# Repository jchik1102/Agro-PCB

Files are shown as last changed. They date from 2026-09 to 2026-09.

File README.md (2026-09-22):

# Agrobot Power Board

Native KiCad schematic and four-layer PCB draft for a regulated 12 V input with separate 5 V and 3.3 V buck converters. Designed as a documented portfolio project; **not a fabrication release or tested hardware**.

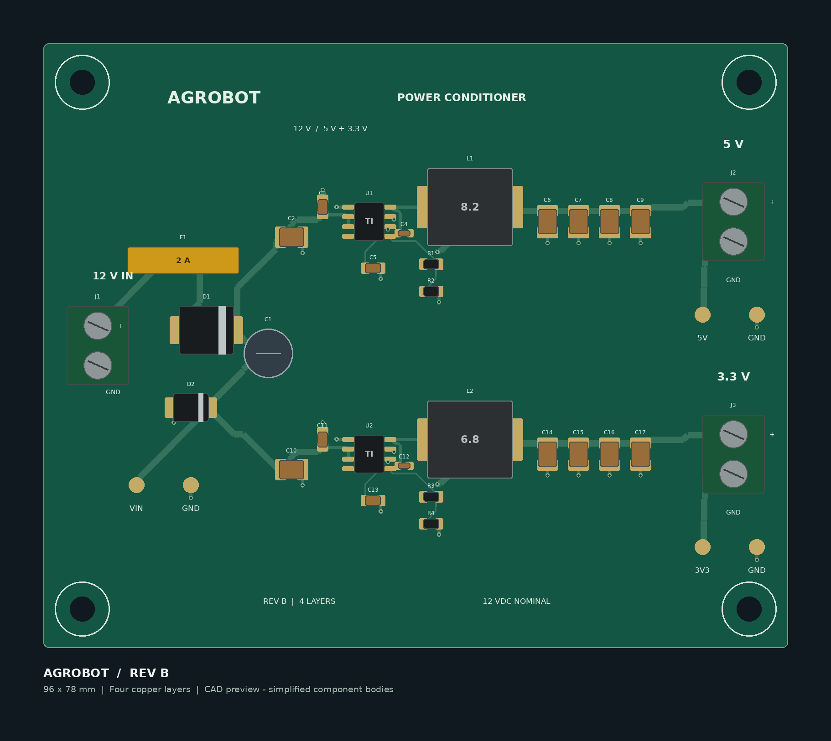
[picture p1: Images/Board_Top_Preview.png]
Board preview


## Open it

1. Install KiCad 9 or newer, including its standard applications.
2. Extract this entire ZIP. Keep the project and Libraries folder together.
3. Open `Agrobot_Power_Board.kicad_pro` in KiCad.
4. Open the schematic with the Schematic Editor button, or the board with the PCB Editor button.
5. In PCB Editor, press **B** to fill the ground zones, then save. If any load/parse error appears, stop and send a screenshot of the complete error.
6. Press **Alt+3** for KiCad's 3D viewer. Included 3D bodies are simplified representations, not manufacturer CAD models.

Ground zones have been defined but are delivered unfilled. Until step 5, ground connections will appear incomplete. The supplied images and PDF are authoring previews, not screenshots or exports from KiCad.

## Requirements and status

| Item | Target / implementation | Evidence status |
| --- | --- | --- |
| Input | Regulated 12 V DC, screw terminal | Nominal design input; not qualified for battery/automotive transients |
| 5 V output | 0.75 A continuous, 1.5 A peak | Design target; load and thermal testing pending |
| 3.3 V output | 0.5 A continuous, 1.0 A peak | Design target; load and thermal testing pending |
| Ripple | 20 mVpp / 10 mVpp respectively, 20 MHz bandwidth | Targets only; not simulated or measured |
| Protection | Resettable input fuse, reverse-polarity diode, TVS clamp | Component-level proposal; coordination review pending |
| Board | 96 x 78 mm, four copper layers, four 3.2 mm mounting holes | Native layout draft |
| Ground | Two internal planes plus outer-layer zones | Fill locally before native DRC |

The two LMR33630 converters use separate inductors, feedback networks, and output capacitors. No microcontroller or sensors are included: this is the Agrobot **power-conditioning board** only. Peak duration is unspecified; no guaranteed peak-duration capability is claimed.

## Contents

- `.kicad_pro`, `.kicad_sch`, `.kicad_pcb`: editable native project.
- `Libraries`: project-local symbols, footprints, simplified 3D models.
- `Documentation/Schematic_Preview.pdf`: immediately viewable schematic preview.
- `Images`: illustrative top-board preview.

## Publishing on GitHub

Upload this folder's contents after reviewing the design. Keep the libraries and relative folder structure intact. The included `.gitignore` excludes local report runs and editor backups. You can deliberately add selected native PDFs, renders, and reviewed reports later.

An accurate project description is: "Developed a KiCad power-conditioning PCB draft for a 12 V input and 5 V/3.3 V outputs, with input protection and documented load/ripple targets. Fabrication and bench validation pending."

Do not describe the ripple or current targets as measured results, or this project as completed in Altium. AI-assisted authoring should be described accurately when relevant to portfolio or academic requirements.

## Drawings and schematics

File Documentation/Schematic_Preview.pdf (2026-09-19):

# AGROBOT / DUAL-RAIL POWER CONDITIONER

## 12 V INPUT | 5 V + 3.3 V | REV B | NATIVE KiCad

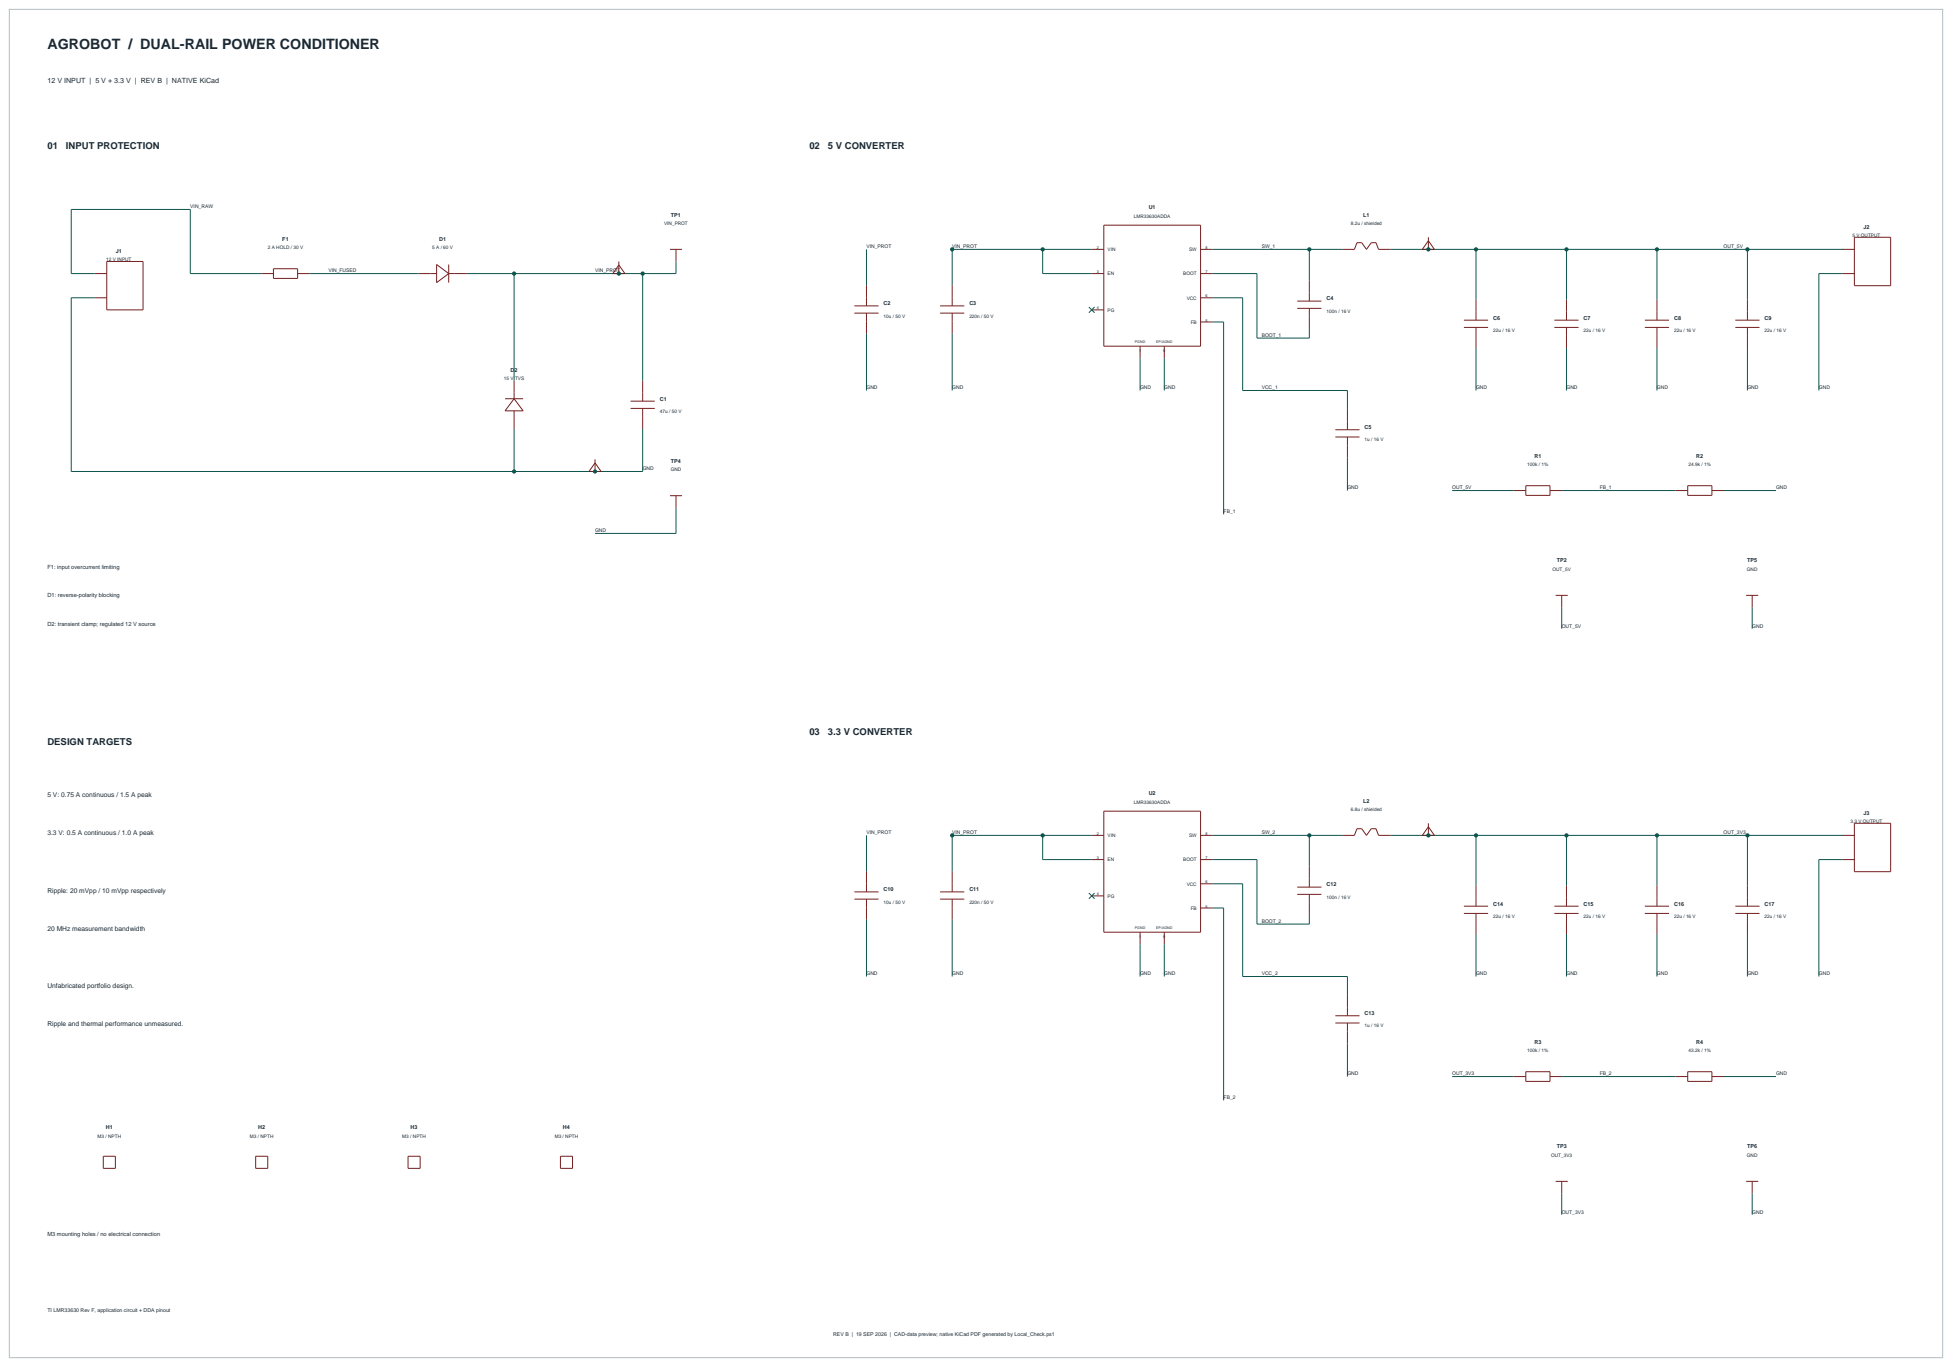
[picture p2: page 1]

D2: transient clamp; regulated 12 V source

Ripple: 20 mVpp / 10 mVpp respectively

Ripple and thermal performance unmeasured.

M3 mounting holes / no electrical connection

TI LMR33630 Rev F, application circuit + DDA pinout

REV B | 19 SEP 2026 | CAD-data preview; native KiCad PDF generated by Local_Check.ps1

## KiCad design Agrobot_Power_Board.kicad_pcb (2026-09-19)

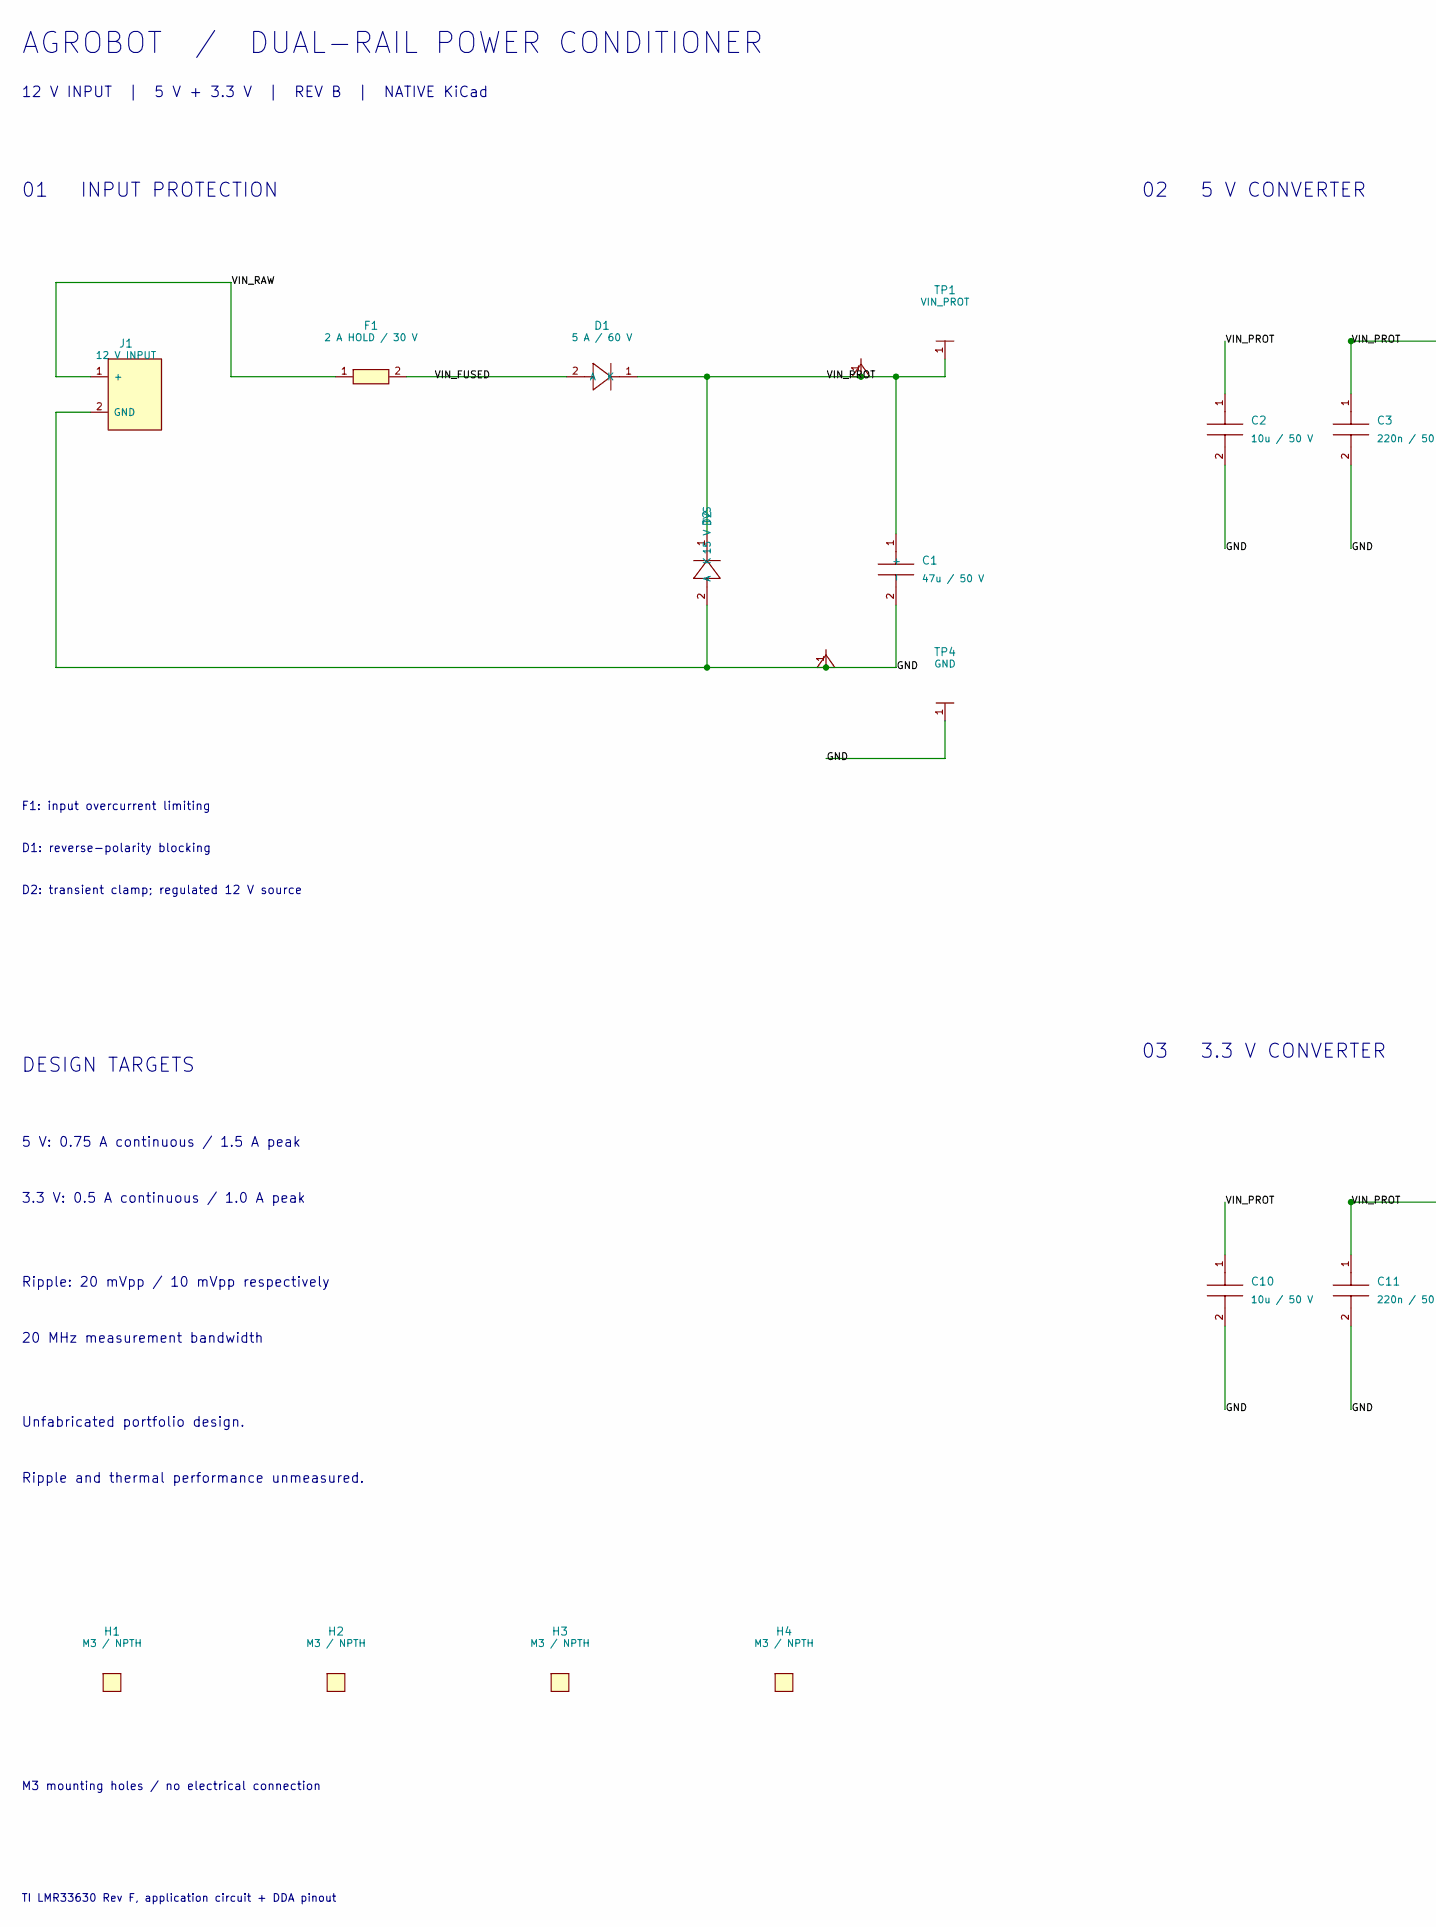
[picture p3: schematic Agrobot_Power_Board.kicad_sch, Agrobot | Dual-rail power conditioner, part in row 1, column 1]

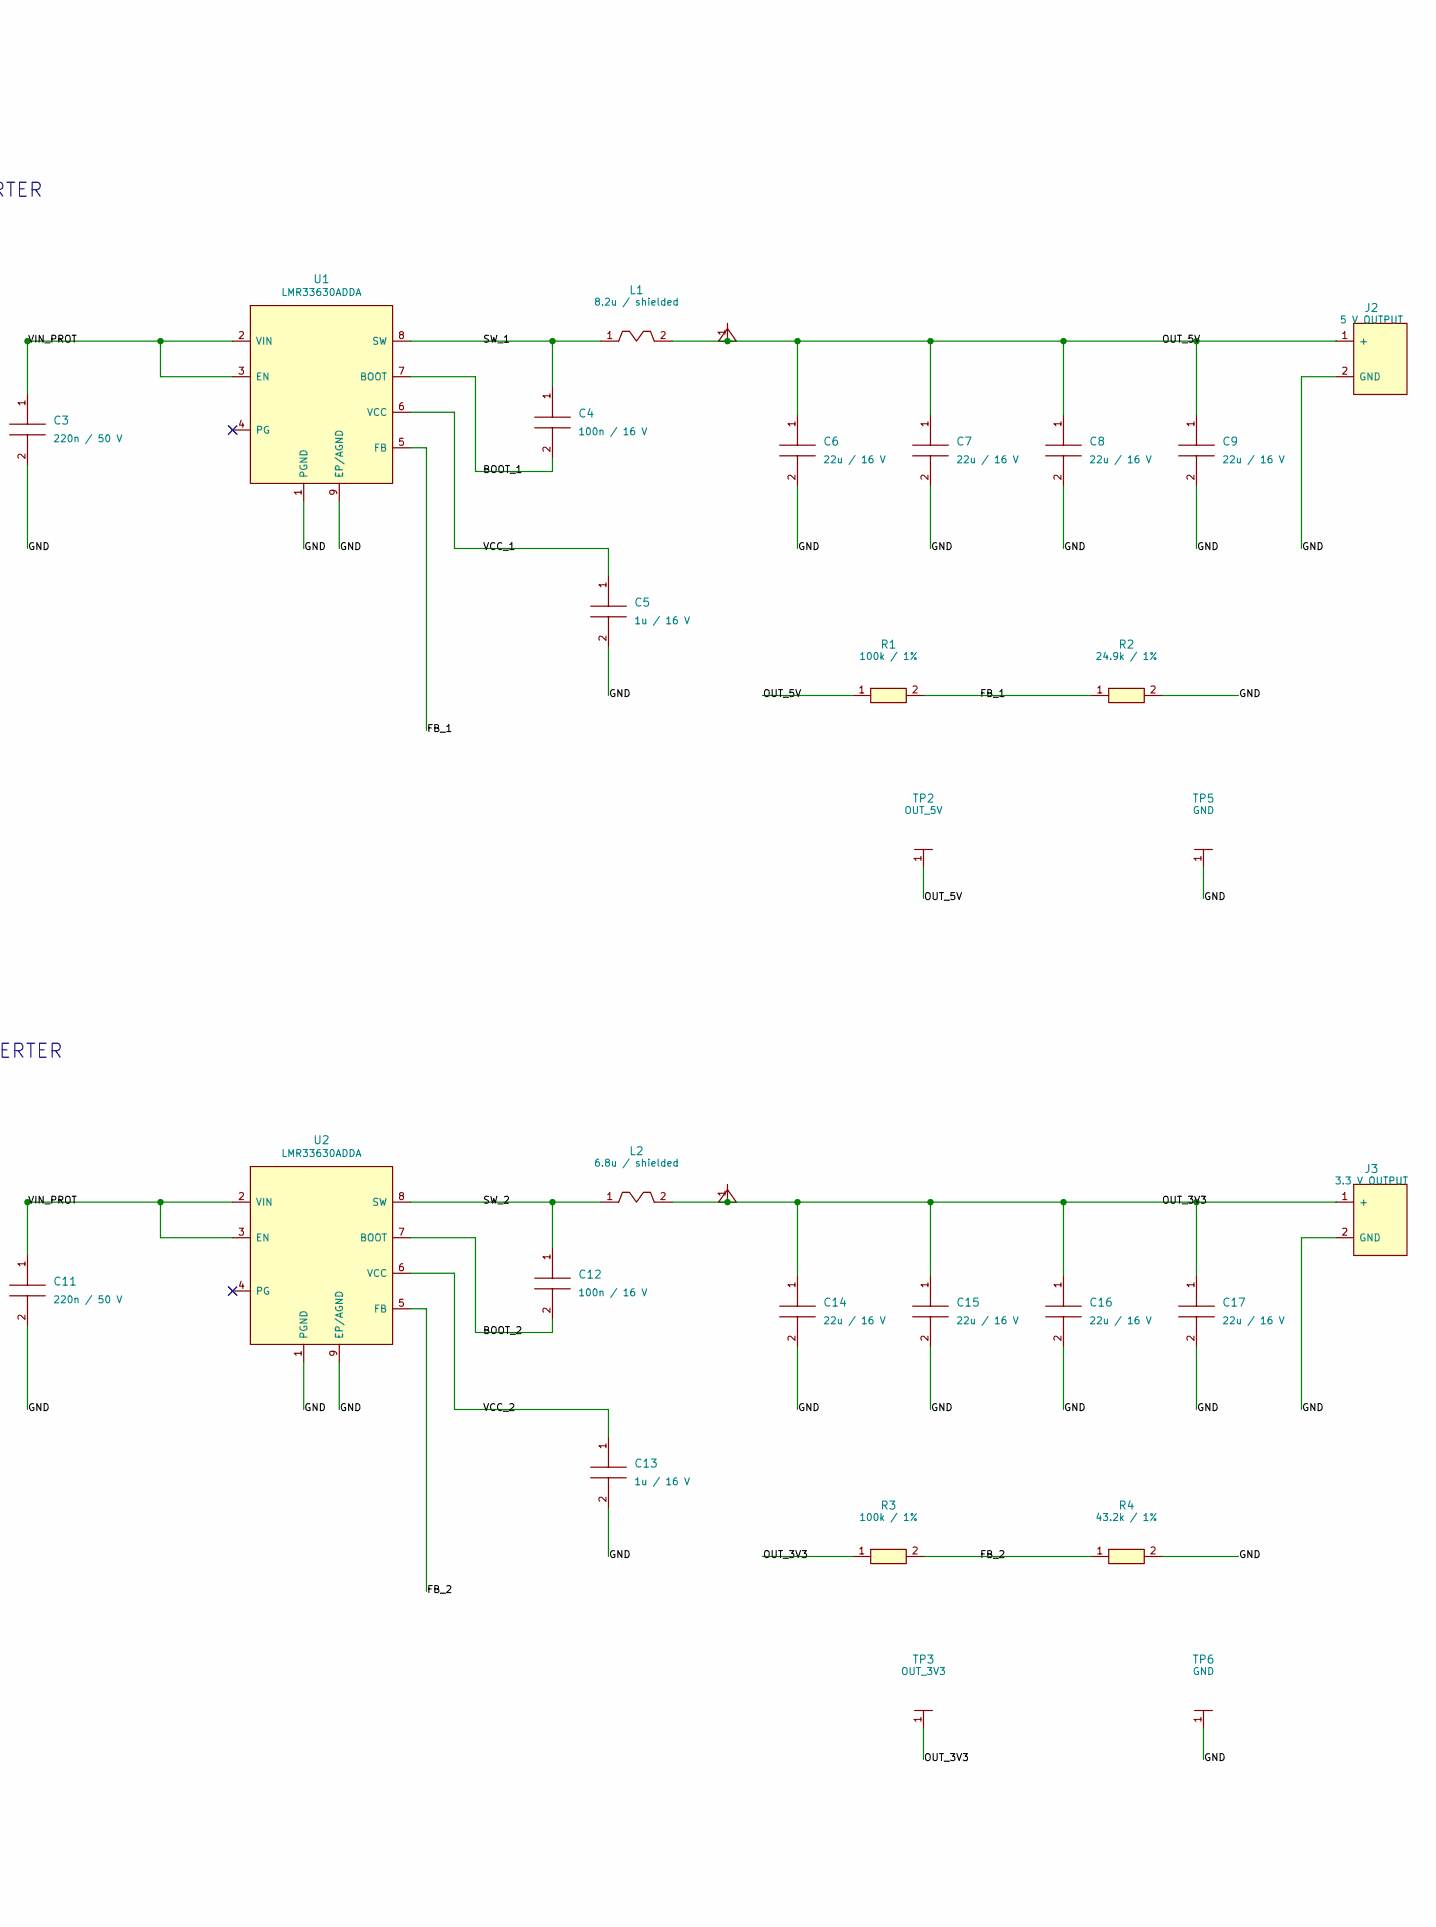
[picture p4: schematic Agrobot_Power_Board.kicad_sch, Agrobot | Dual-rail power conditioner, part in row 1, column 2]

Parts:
C1: 47u / 50 V; Electro; MPN EEU-FR1H470
C2, C10: 10u / 50 V; C1210; MPN GRM32ER71H106KA12L
C3, C11: 220n / 50 V; C0805; MPN 0805 X7R 220nF 50V
C4, C12: 100n / 16 V; C0603; MPN 0603 X7R 100nF 16V
C5, C13: 1u / 16 V; C0805; MPN 0805 X7R 1uF 16V
C6, C7, C8, C9, C14, C15, C16, C17: 22u / 16 V; C1210; MPN 1210 X7R 22uF 16V
D1: 5 A / 60 V; SMC; MPN SS56-E3/57T
D2: 15 V TVS; SMB; MPN SMBJ15A
F1: 2 A HOLD / 30 V; PTC; MPN MF-R200
H1, H2, H3, H4: M3 / NPTH; Hole; MPN 3.2 mm non-plated hole
J1: 12 V INPUT; Terminal; MPN KF301-5.08-2P
J2: 5 V OUTPUT; Terminal; MPN KF301-5.08-2P
J3: 3.3 V OUTPUT; Terminal; MPN KF301-5.08-2P
L1: 8.2u / shielded; Inductor; MPN SRP1038A-8R2M
L2: 6.8u / shielded; Inductor; MPN SRP1038A-6R8M
R1, R3: 100k / 1%; R0805; MPN 0805 100k 1%
R2: 24.9k / 1%; R0805; MPN 0805 24.9k 1%
R4: 43.2k / 1%; R0805; MPN 0805 43.2k 1%
TP1: VIN_PROT; TP; MPN PCB test pad 2 mm
TP2: OUT_5V; TP; MPN PCB test pad 2 mm
TP3: OUT_3V3; TP; MPN PCB test pad 2 mm
TP4, TP5, TP6: GND; TP; MPN PCB test pad 2 mm
U1, U2: LMR33630ADDA; DDA; MPN LMR33630ADDAR

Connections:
BOOT_1: C4.2, U1.7
BOOT_2: C12.2, U2.7
FB_1: R1.2, R2.1, U1.5
FB_2: R3.2, R4.1, U2.5
GND: C1.2, C2.2, C3.2, C5.2, C6.2, C7.2, C8.2, C9.2, C10.2, C11.2, C13.2, C14.2, C15.2, C16.2, C17.2, D2.2, J1.2, J2.2, J3.2, R2.2, R4.2, TP4.1, TP5.1, TP6.1, U1.1, U1.9, U2.1, U2.9
OUT_3V3: C14.1, C15.1, C16.1, C17.1, J3.1, L2.2, R3.1, TP3.1
OUT_5V: C6.1, C7.1, C8.1, C9.1, J2.1, L1.2, R1.1, TP2.1
PG_1: U1.4
PG_2: U2.4
SW_1: C4.1, L1.1, U1.8
SW_2: C12.1, L2.1, U2.8
VCC_1: C5.1, U1.6
VCC_2: C13.1, U2.6
VIN_FUSED: D1.2, F1.2
VIN_PROT: C1.1, C2.1, C3.1, C10.1, C11.1, D1.1, D2.1, TP1.1, U1.2, U1.3, U2.2, U2.3
VIN_RAW: F1.1, J1.1

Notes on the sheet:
AGROBOT / DUAL-RAIL POWER CONDITIONER
12 V INPUT | 5 V + 3.3 V | REV B | NATIVE KiCad
01 INPUT PROTECTION
F1: input overcurrent limiting
D1: reverse-polarity blocking
D2: transient clamp; regulated 12 V source
02 5 V CONVERTER
03 3.3 V CONVERTER
DESIGN TARGETS
5 V: 0.75 A continuous / 1.5 A peak
3.3 V: 0.5 A continuous / 1.0 A peak
Ripple: 20 mVpp / 10 mVpp respectively
20 MHz measurement bandwidth
Unfabricated portfolio design.
Ripple and thermal performance unmeasured.
M3 mounting holes / no electrical connection
TI LMR33630 Rev F, application circuit + DDA pinout

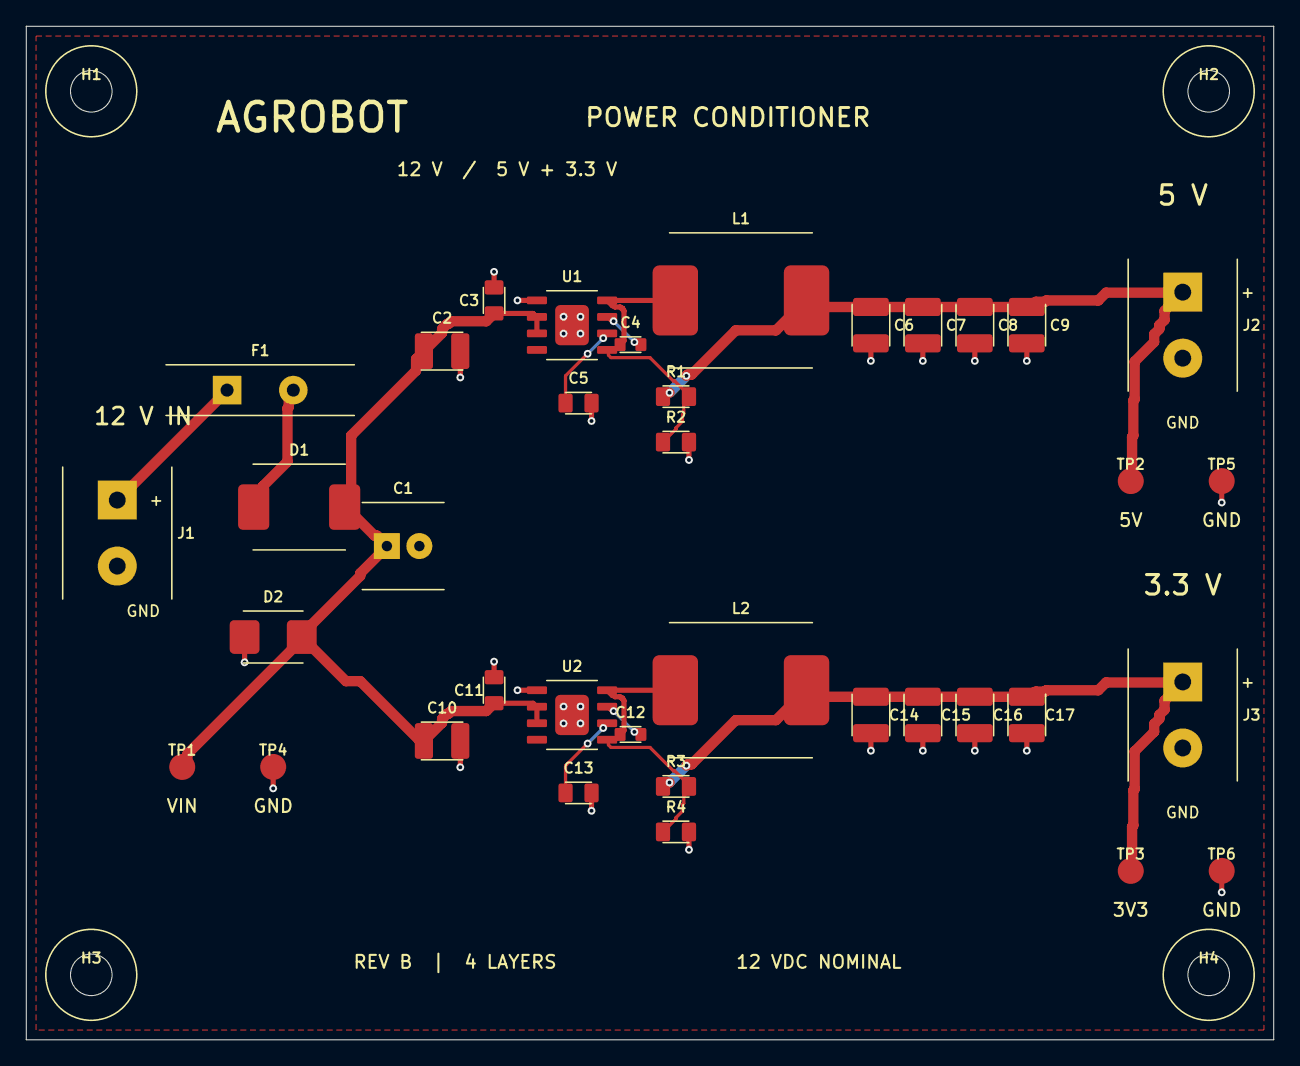
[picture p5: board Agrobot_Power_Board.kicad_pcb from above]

Board: 4 copper layers, 96.0 x 78.0 mm, 41 parts (0 on the bottom side), 14 nets.
